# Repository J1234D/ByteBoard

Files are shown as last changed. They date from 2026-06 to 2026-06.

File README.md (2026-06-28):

# ByteBoard

ByteBoard is my custom 3×3 mechanical macropad powered by the Seeed Studio XIAO RP2040. It has 9 programmable mechanical keys, a rotary encoder, a 0.91" OLED display, per-key RGB lighting, and a custom PCB and 3D-printed case that I designed from scratch.

I started this project as part of Hack Club Stardance because I wanted to learn PCB design, CAD, and keyboard firmware by building something I would actually use. Instead of modifying an existing design, I challenged myself to design everything—from the schematic and PCB to the enclosure and firmware.

The result is a compact macropad that's useful for coding, video editing, media controls, and everyday shortcuts while also being a fun project to customize. Since everything is open source, you can easily change the firmware, modify the hardware, or even design your own version.

➡️ [Read the full journal](./JOURNAL.md)

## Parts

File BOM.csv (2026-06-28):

Id | Designator | Footprint | Quantity | Designation | Supplier and ref | Notes
1 | D1, D2, D3, D4, D5, D6, D7, D8, D9 | D_DO-35_SOD27_P7.62mm_Horizontal | 9 | 1N4148 |  | Included in Hackpad Kit
2 | D10, D11, D12, D13, D14, D15, D16, D17, D18 | LED_SK6812MINI-E_3.2x2.8mm_P1.5mm_ReverseMount | 9 | SK6812MINI-E |  | Included in Hackpad Kit
3 | SW1, SW2, SW3, SW4, SW5, SW6, SW7, SW8, SW9 | SW_Cherry_MX_1.00u_PCB_Custom | 9 | MX Switch |  | Included in Hackpad Kit
4 | SW10 | RotaryEncoder_Alps_EC11E-Switch_Vertical_H20mm | 1 | EC11 Rotary Encoder |  | Included in Hackpad Kit
5 | U1 | XIAO-Generic-Hybrid-14P-2.54-21X17.8MM | 1 | Seeed Studio XIAO RP2040 |  | Included in Hackpad Kit
6 | U2 | ER_OLEDM0.91_1x-I2C | 1 | 0.91 inch I2C OLED |  | Included in Hackpad Kit
7 | Soldering Station | N/A | 1 | YIHUA 926LED-III 60W Digital Soldering Station | https://robu.in/product/yihua-926led-iii-60w-digital-soldering-iron-tools/ | Required for assembly (not included in Hackpad Kit)

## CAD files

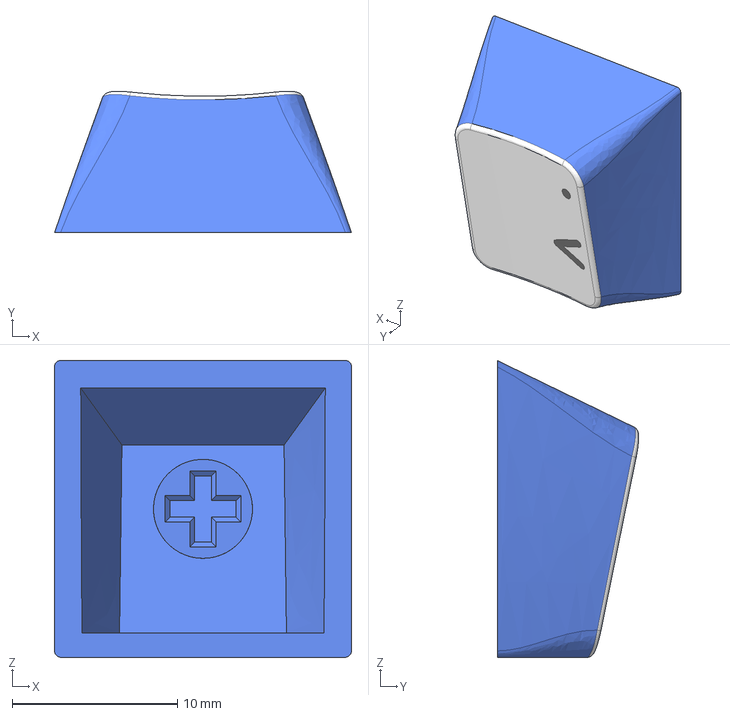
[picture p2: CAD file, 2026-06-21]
assets/CherryMX-master/r4 legended/STP/FULL STOP.stp
18.0 x 8.57 x 18.0 mm

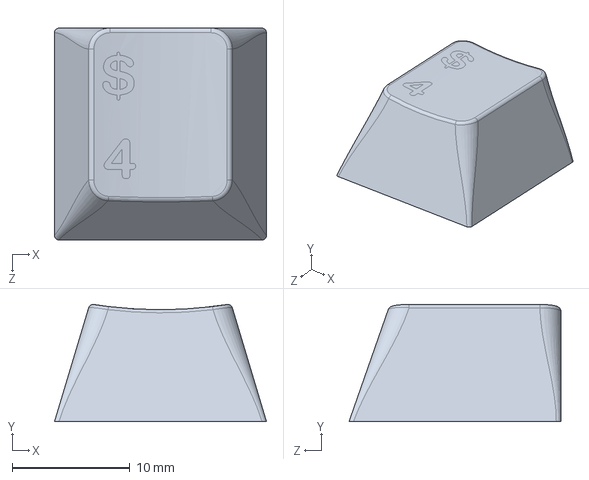
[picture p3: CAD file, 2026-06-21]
assets/CherryMX-master/r1 legended/SLDPRT/4_NEW.SLDPRT
18.0 x 9.95 x 18.0 mm

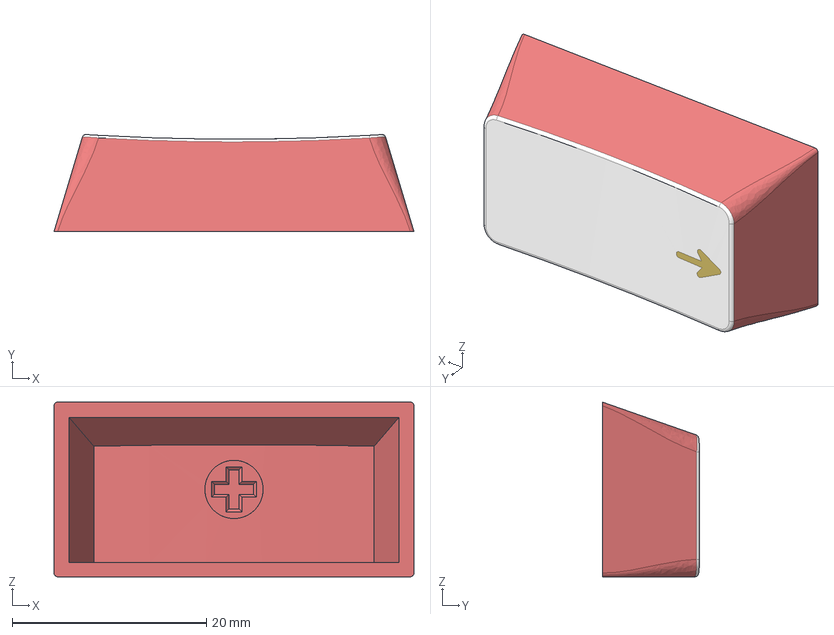
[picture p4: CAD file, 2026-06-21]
assets/CherryMX-master/r1 legended/STP/2/Backspace icon.stp
37.1 x 9.98 x 18.0 mm

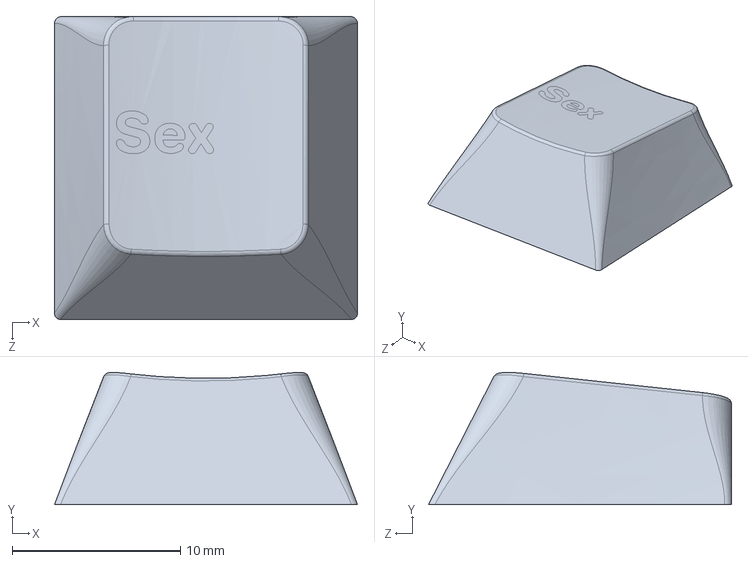
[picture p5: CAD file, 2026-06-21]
assets/CherryMX-master/r2 legended/SLDPRT/sex.SLDPRT
18.0 x 7.85 x 18.0 mm

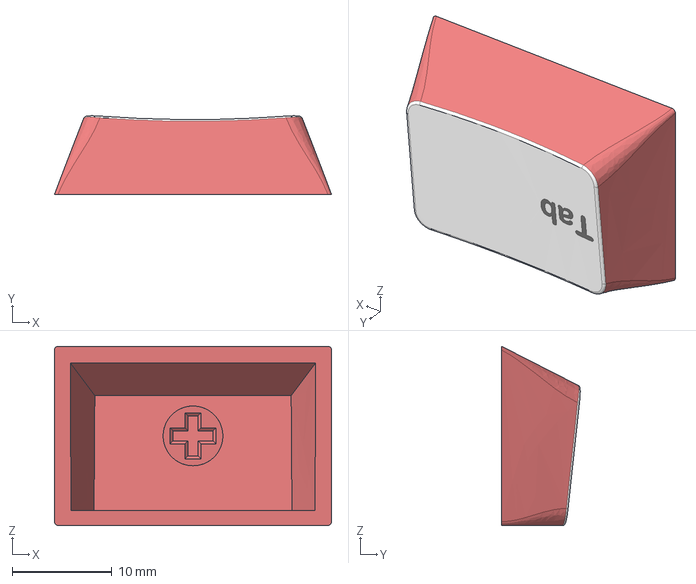
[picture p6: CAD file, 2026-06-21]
assets/CherryMX-master/r2 legended/STP/15/Tab text.stp
27.8 x 7.88 x 18.0 mm

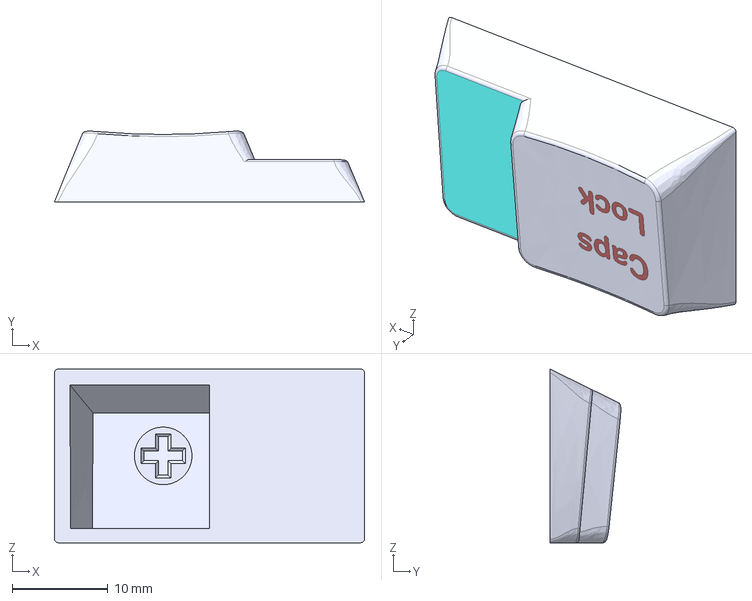
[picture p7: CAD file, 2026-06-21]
assets/CherryMX-master/r3 legended/STP/175/caps_lock_stepped.stp
32.3 x 7.36 x 18.1 mm

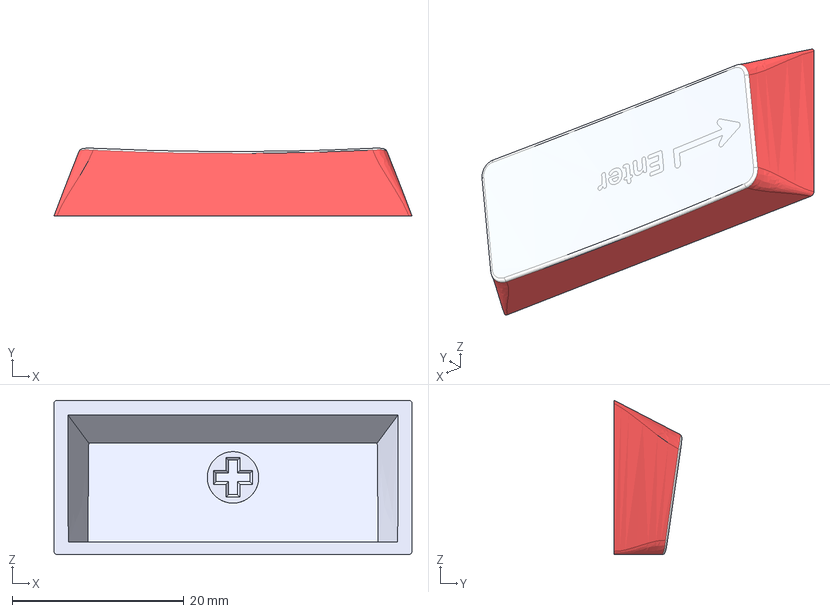
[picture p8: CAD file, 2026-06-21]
assets/CherryMX-master/r3 legended/STP/225/Enter Icon and Text 225.stp
41.7 x 7.89 x 18.0 mm

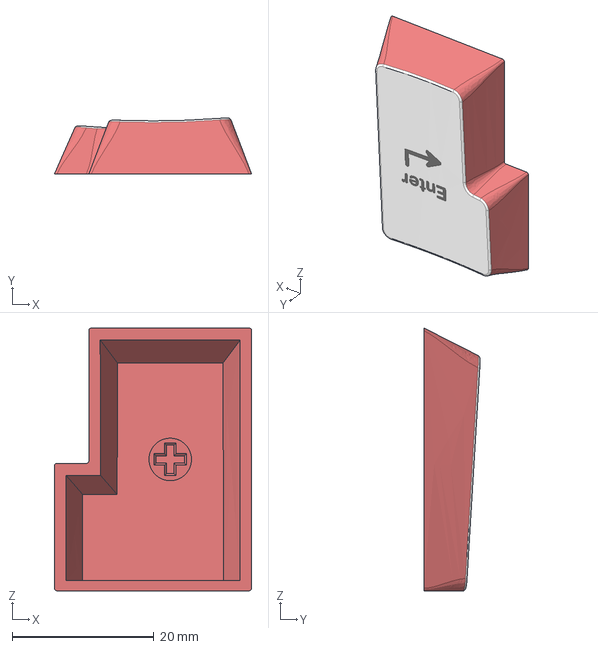
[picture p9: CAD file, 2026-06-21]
assets/CherryMX-master/r3 legended/STP/iso/Enter Icon and Text.stp
27.8 x 7.91 x 37.1 mm

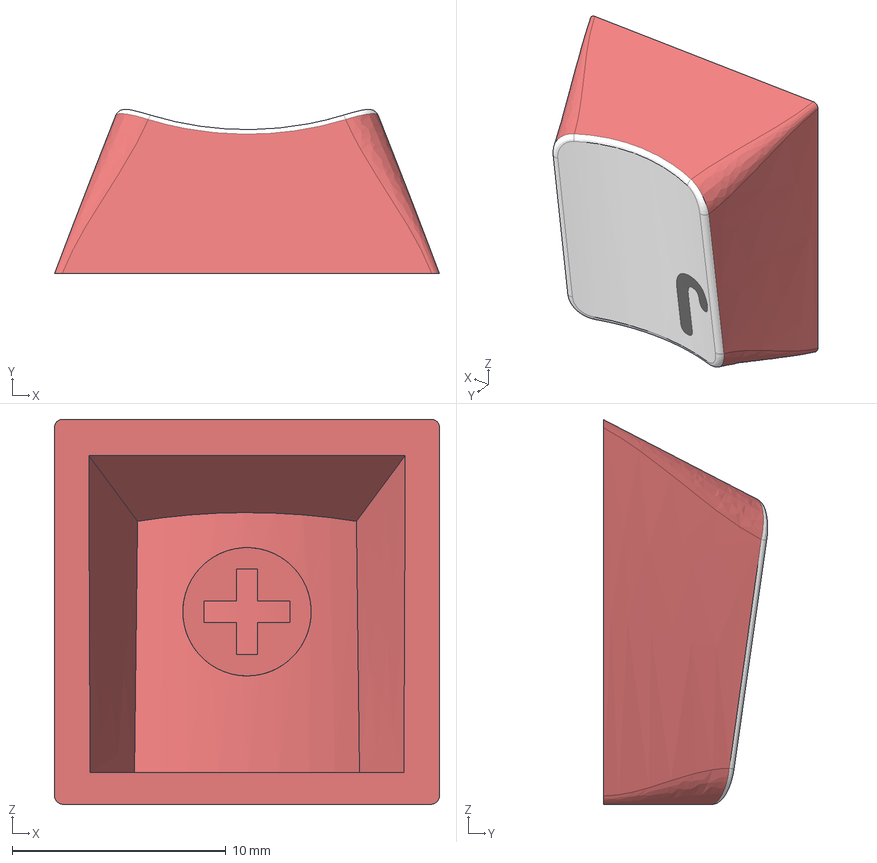
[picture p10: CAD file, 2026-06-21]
assets/CherryMX-master/r3 legended/STP/sculpted/J.stp
18.0 x 7.68 x 18.0 mm

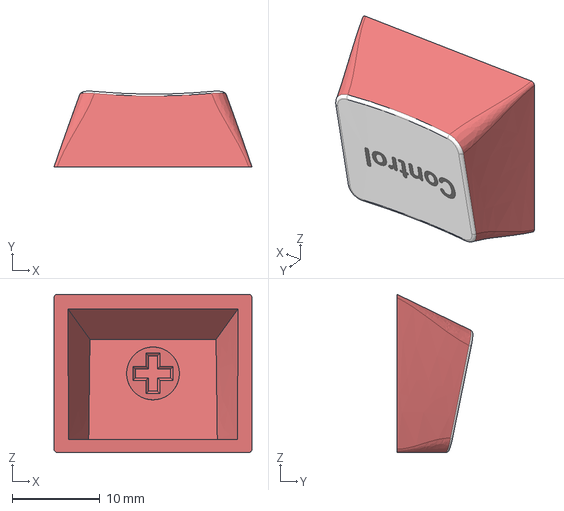
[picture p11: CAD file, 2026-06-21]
assets/CherryMX-master/r4 legended/STP/125/Control.stp
22.5 x 8.61 x 18.0 mm

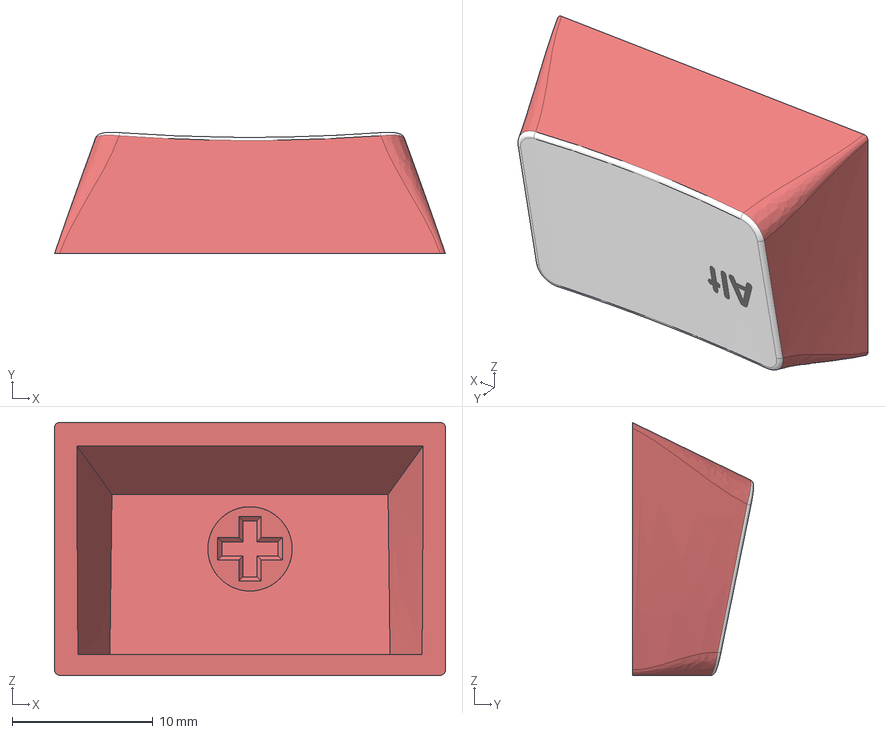
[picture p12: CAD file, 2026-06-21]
assets/CherryMX-master/r4 legended/STP/15/Alt.stp
27.8 x 8.63 x 18.0 mm

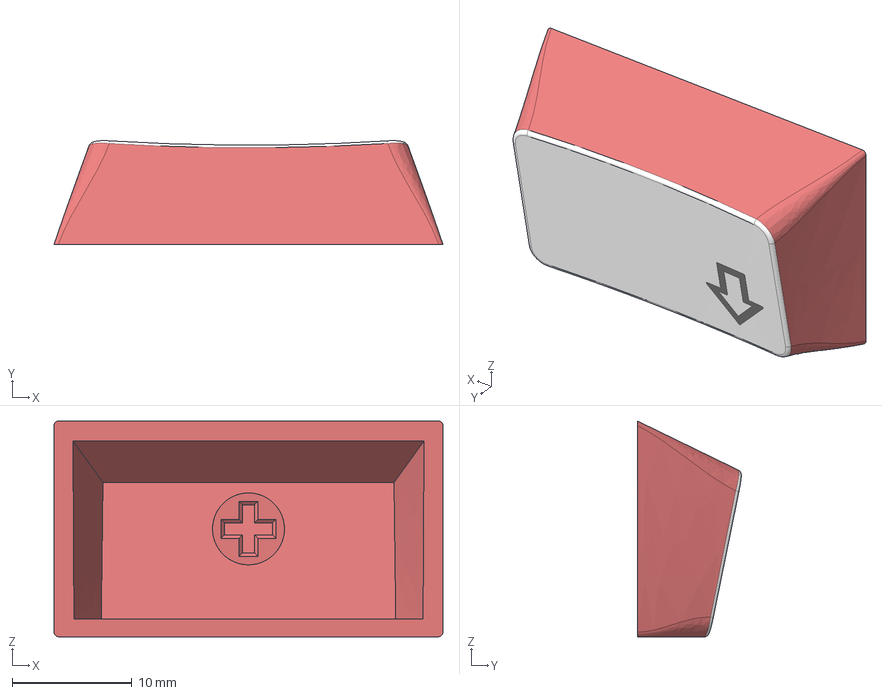
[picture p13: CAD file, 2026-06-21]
assets/CherryMX-master/r4 legended/STP/175/Shift short icon.stp
32.4 x 8.65 x 18.0 mm

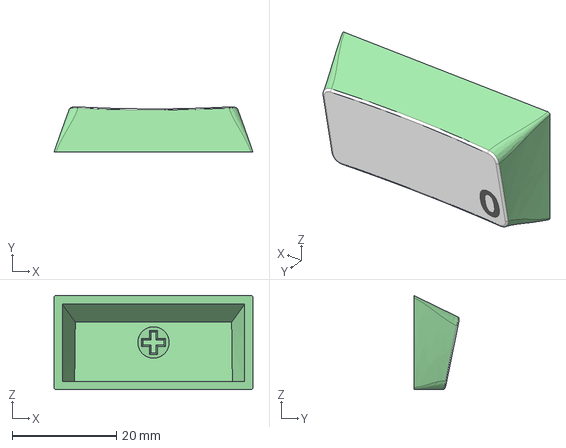
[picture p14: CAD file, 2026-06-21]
assets/CherryMX-master/r4 legended/STP/200/num0_200_mono.stp
38.1 x 8.66 x 18.0 mm

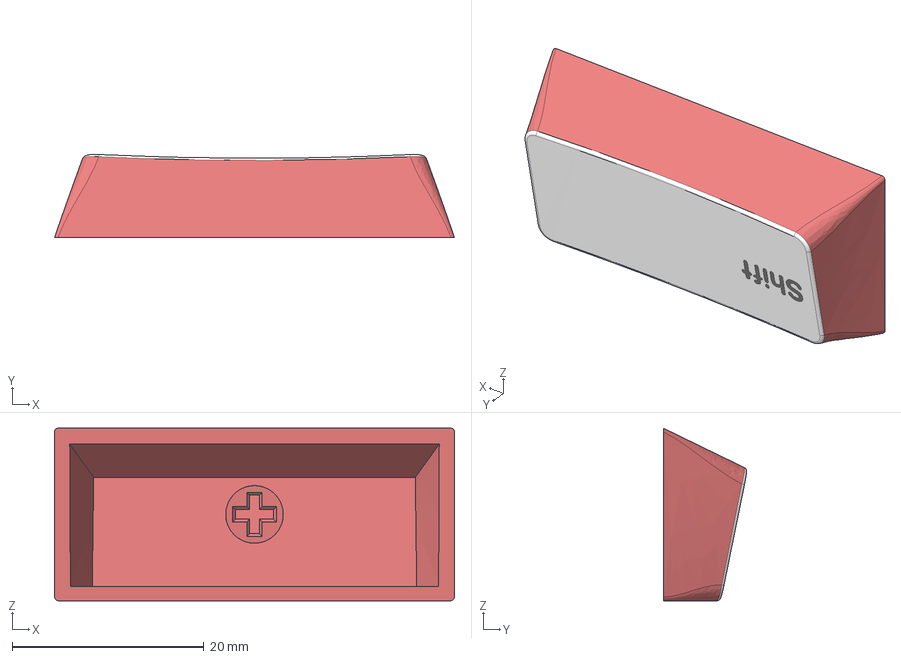
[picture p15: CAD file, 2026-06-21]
assets/CherryMX-master/r4 legended/STP/225/Shift text.stp
41.7 x 8.67 x 18.0 mm

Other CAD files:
assets/CherryMX-master/r1 legended/STP/NUM Divide.stp
assets/CherryMX-master/r2 legended/STP/NUM Minus.stp
assets/CherryMX-master/r3 legended/STP/NUM 5_homing_bar.stp
assets/CherryMX-master/r4 legended/STP/275/Shift icon and text.stp
CAD/Bottom_Case.step
CAD/Top_Case.step
assets/CherryMX-master/SLDPRT/r1/r1_100.SLDPRT
assets/CherryMX-master/SLDPRT/r1/r1_200.SLDPRT
assets/CherryMX-master/SLDPRT/r2/r2_100.SLDPRT
assets/CherryMX-master/SLDPRT/r2/r2_150.SLDPRT
assets/CherryMX-master/SLDPRT/r3/r2-3_200vert.SLDPRT
assets/CherryMX-master/SLDPRT/r3/r3_100.SLDPRT
assets/CherryMX-master/SLDPRT/r3/r3_100_bar.SLDPRT
assets/CherryMX-master/SLDPRT/r3/r3_100_sculpted.SLDPRT
assets/CherryMX-master/SLDPRT/r3/r3_125.SLDPRT
assets/CherryMX-master/SLDPRT/r3/r3_150.SLDPRT
assets/CherryMX-master/SLDPRT/r3/r3_175.SLDPRT
assets/CherryMX-master/SLDPRT/r3/r3_175_stepped.SLDPRT
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

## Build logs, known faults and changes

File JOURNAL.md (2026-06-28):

# 🎛️ ByteBoard

> A custom RGB macropad powered by the Seeed Studio XIAO RP2040.

**Author:** Jishnu Dutta
**Started:** 19 June 2026
**Progress:** 🟩🟩🟩🟩🟩🟩🟩⬜⬜⬜ 70%
**Current Stage:** Waiting for Kit

---

## 📖 Overview

ByteBoard is a custom macropad built around the Seeed Studio XIAO RP2040. It features 9 mechanical keys, SK6812 MINI-E RGB LEDs, a rotary encoder, and an OLED display for customizable controls and visual feedback. The goal of this project is to create a compact and visually appealing productivity tool while learning PCB design, electronics, and firmware development.

---

## 📅 Devlogs

# Day 0 — 19.06.2026: Planning & Studying

Just a few days ago, my friend Sunrit Hazra showed me his custom macropad, which he had built using Hack Club Blueprint. Seeing his project and hearing about the experience inspired me to build one of my own.

Today, I decided to start the project, so I learned the basics of PCB design and schematic creation. I also made a small PCB with 4 LEDs and 2 connectors.

Time spent: 3hrs

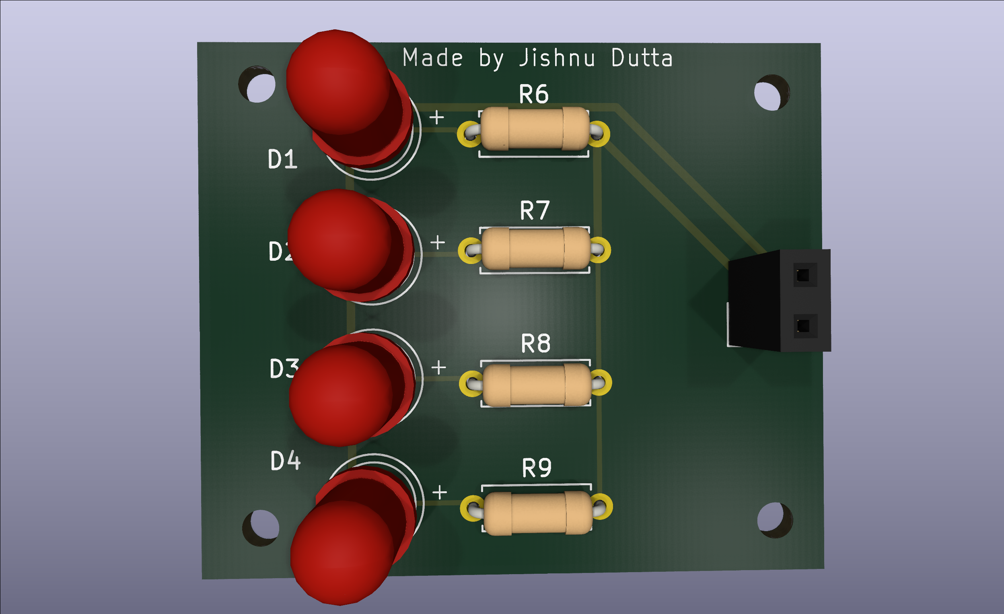
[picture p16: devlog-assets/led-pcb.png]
LED PCB


# Day 1 — 20.06.2026: Schematic

I created the 3×3 key matrix and connected it to the Seeed Studio XIAO RP2040. I also added the rotary encoder and OLED display.

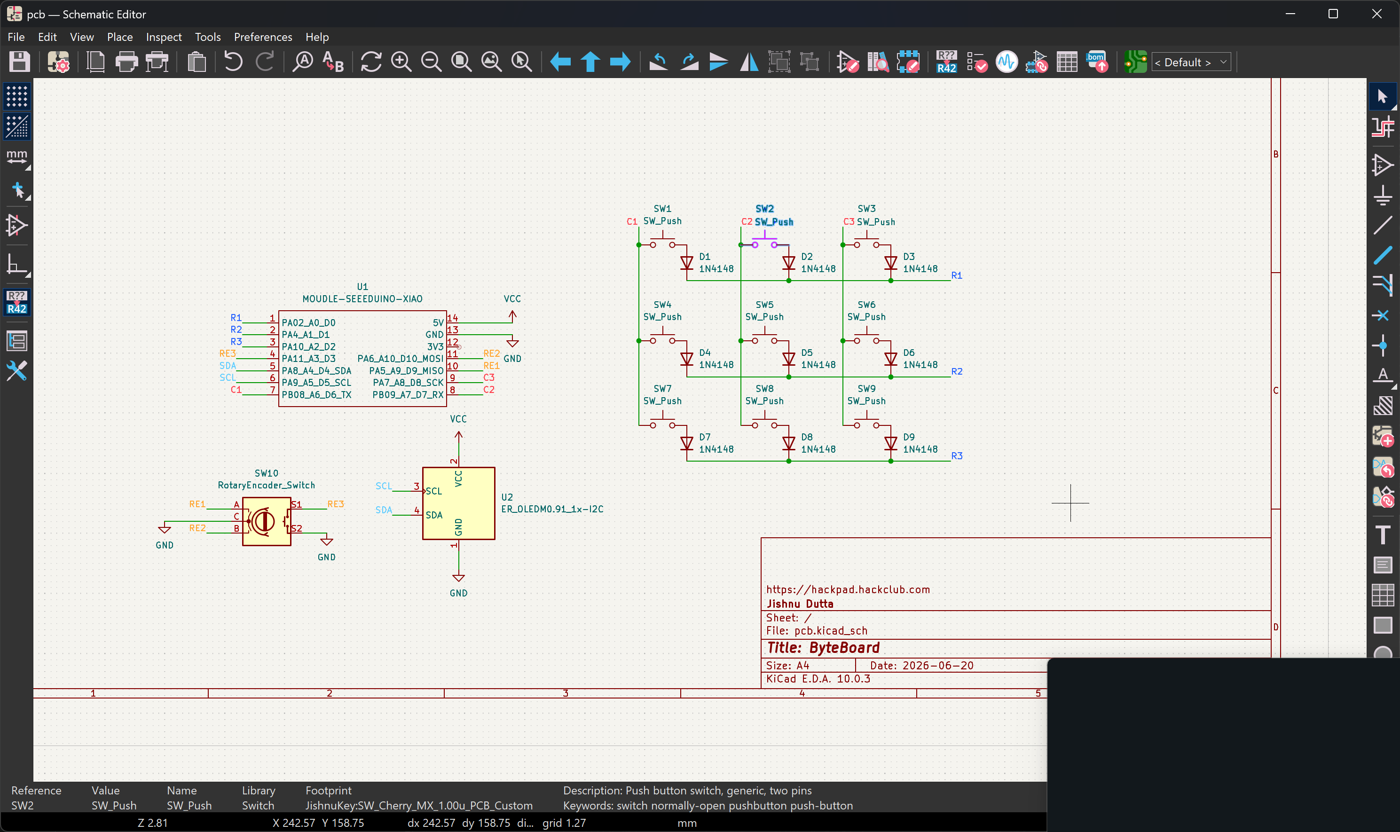
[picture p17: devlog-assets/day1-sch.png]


Time spent: 5hrs

# Day 2 — 21.06.2026: Schematic and Routing

I added SK6812 MINI-E LEDs around the edges of each key for a nice underglow effect, along with mounting holes. After that, I designed the PCB and completed the routing.

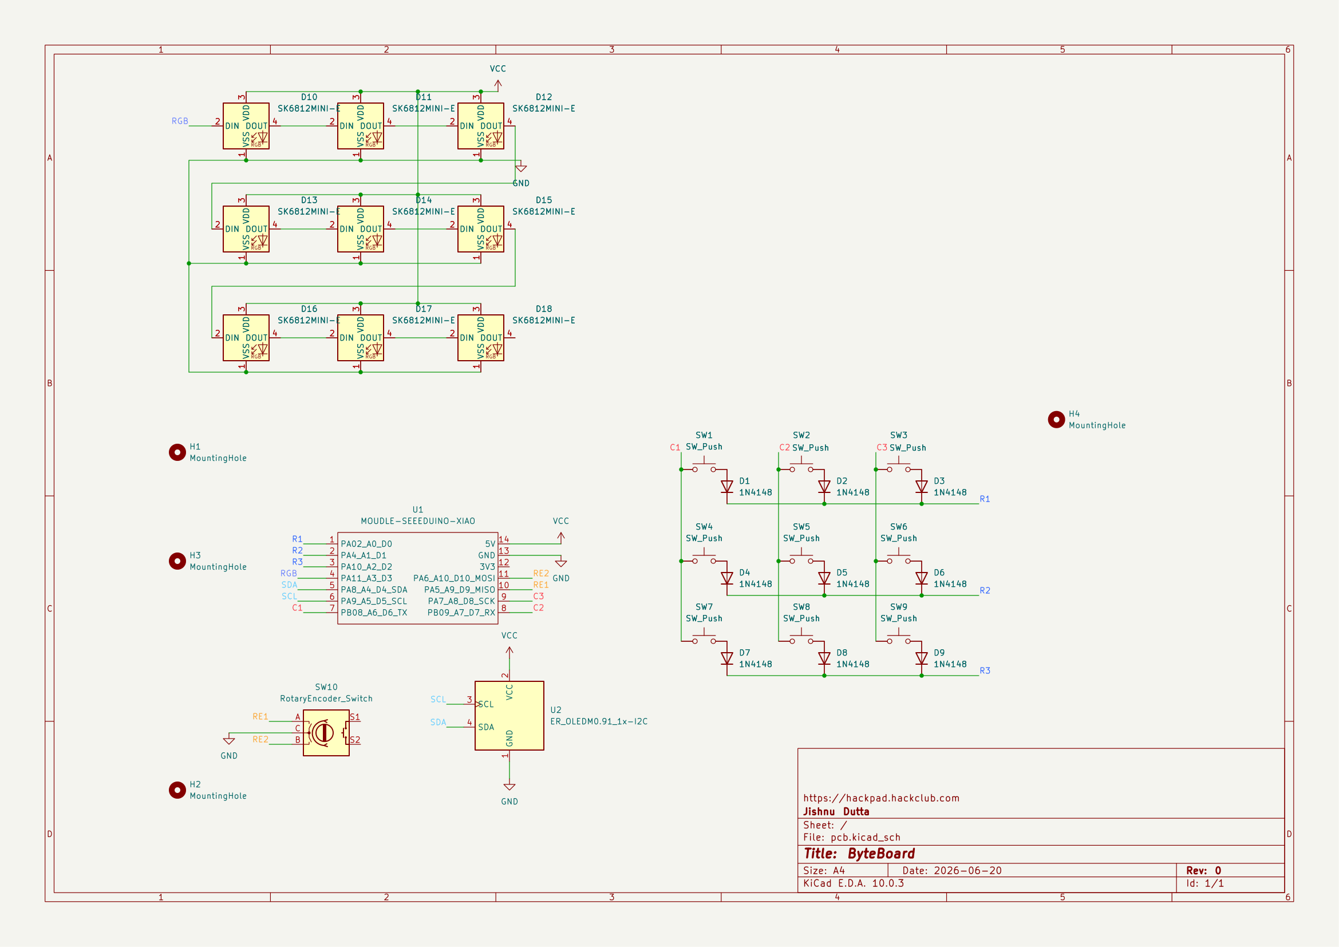
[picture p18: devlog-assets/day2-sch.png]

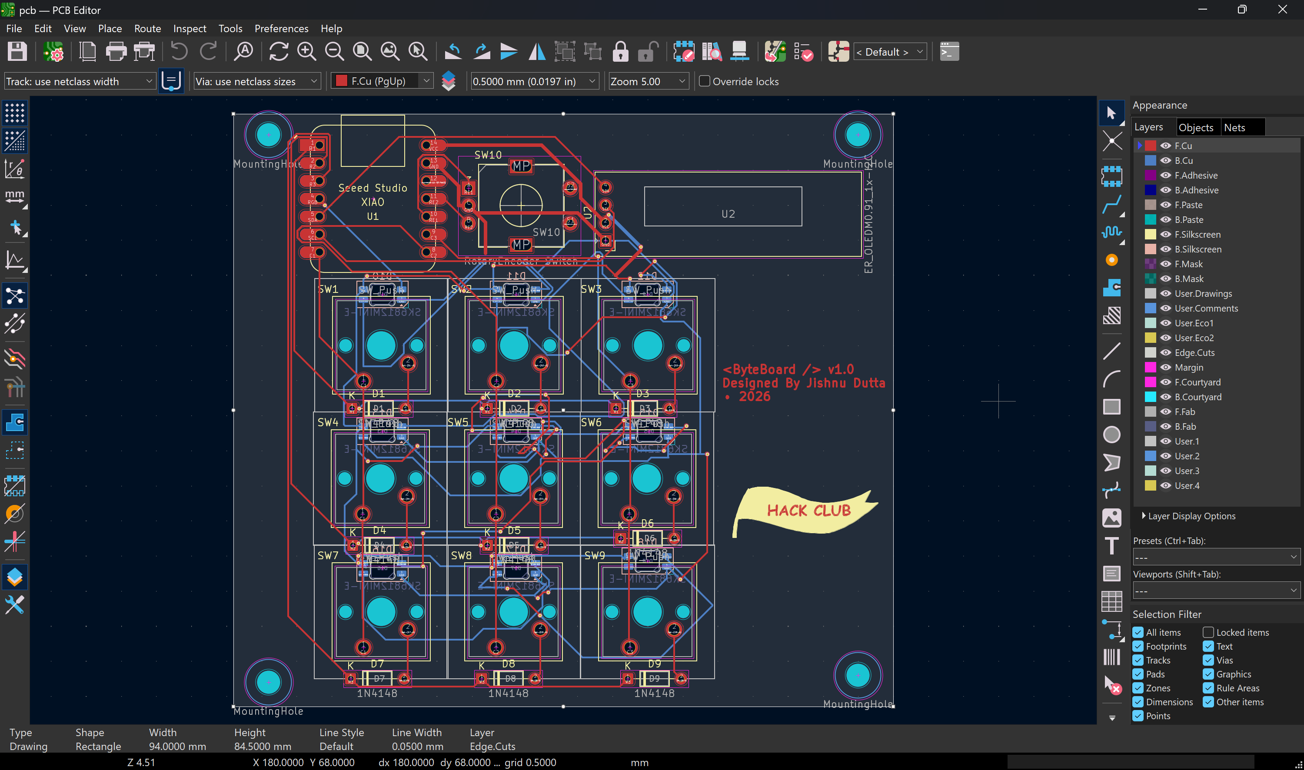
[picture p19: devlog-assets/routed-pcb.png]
PCB

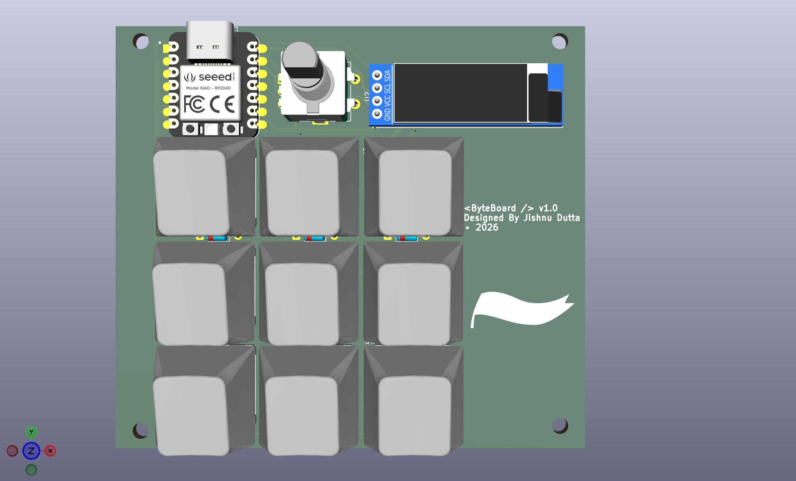
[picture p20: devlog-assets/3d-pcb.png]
3D model of PCB


Time spent: 8hrs

# Day 3 — 22.06.2026: Learning Fusion

I learned the basics of 3D modeling in Autodesk Fusion by following a tutorial and creating a small screw bracket.

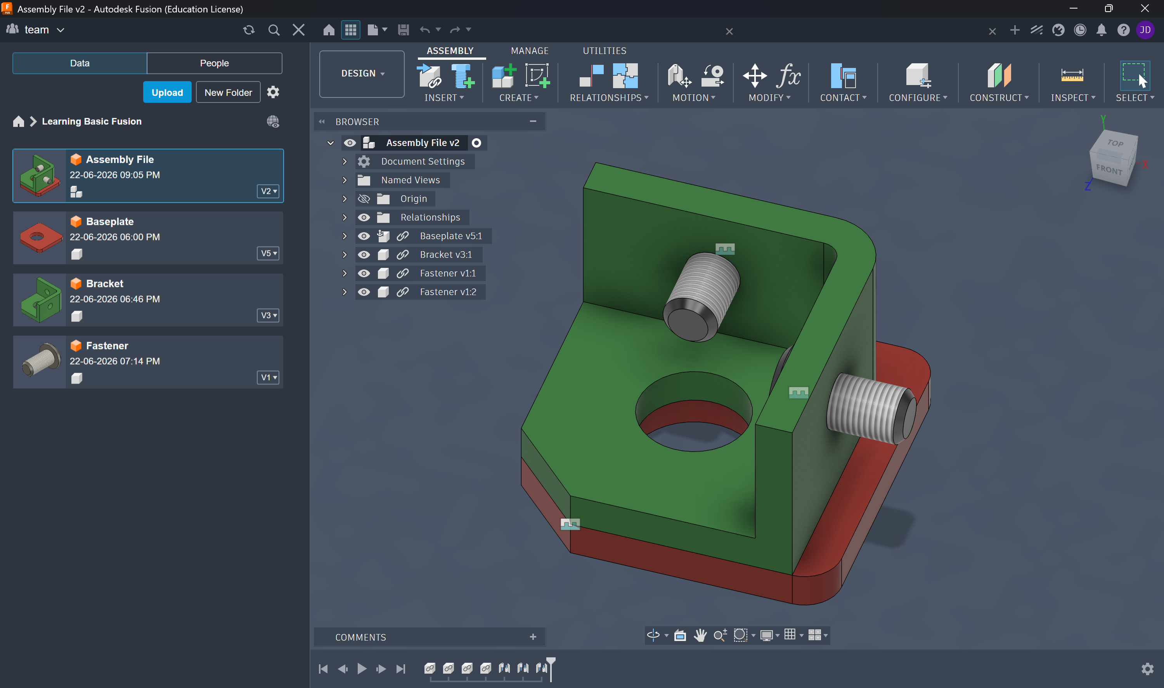
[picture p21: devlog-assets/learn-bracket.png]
bracket


Time spent: 2hrs

Sorry for not recording timelapses during the first three days. I will provide timelapse links for every day from now on.

# Day 4 — 23.06.2026: Starting the Case and Learning Fusion Tools

I researched the soldering equipment I might need for this project and started designing the bottom plate of the case. 

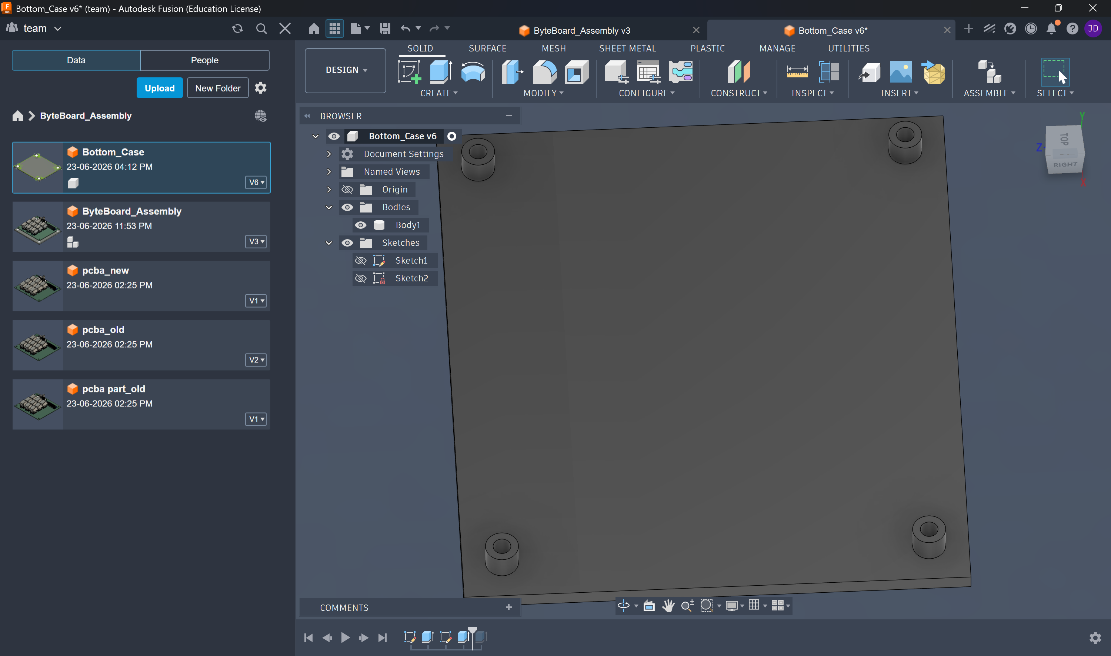
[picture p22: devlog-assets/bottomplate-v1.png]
bottomplate


Time spent: 7hrs

Lapse link: <a href="https://lapse.hackclub.com/timelapse/p2R1_J-4u7W7">Day 4</a>

# Day 5 — 25.06.2026: Fixing the Case 
I fixed the standoffs, added walls in the bottom part of the case. I also had to fix many clearance issues to make the usb type c port usable.

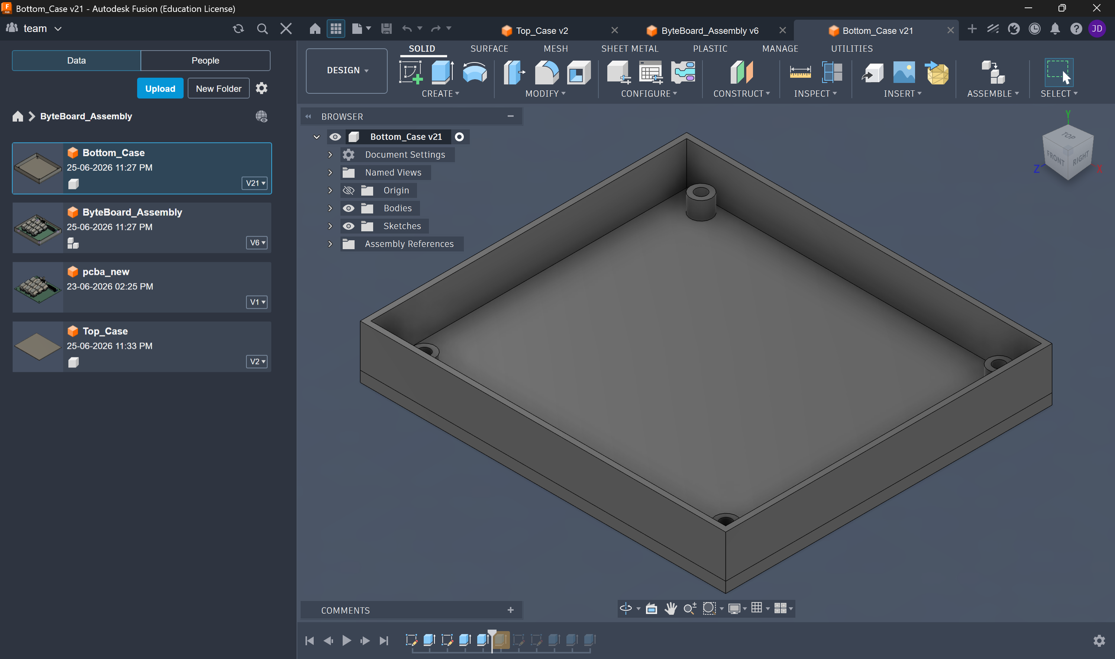
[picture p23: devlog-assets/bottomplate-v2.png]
pcb with bottomplate


Time spent: 3 hrs

Lapse link: <a href="https://lapse.hackclub.com/timelapse/Zt0mHt_HGtjv">Day 5</a>

# Day 6 — 26.06.2026: Designing the Top Case

Today I finished designing the top case. I added all the required cutouts, including the MX switch openings, OLED display window, rotary encoder hole, USB Type-C port opening, and the mounting holes. Getting the clearances right took quite a bit of tweaking, especially around the USB port.

> **Note:** The Lapse website was offline for most of the day, so I could only record about **30 minutes**, even though I worked for **around 3 hours**.

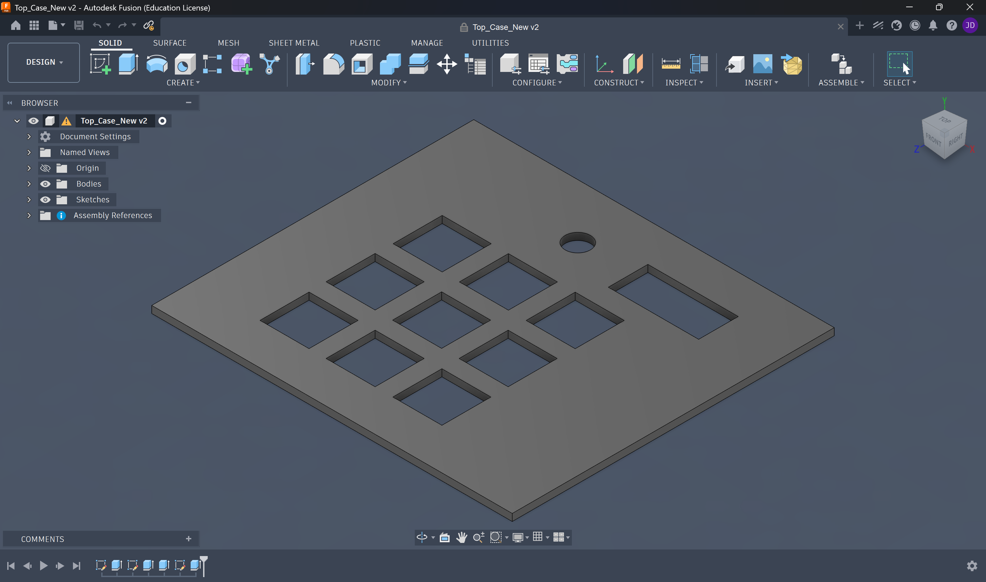
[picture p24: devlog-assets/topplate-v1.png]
Top case with all cutouts

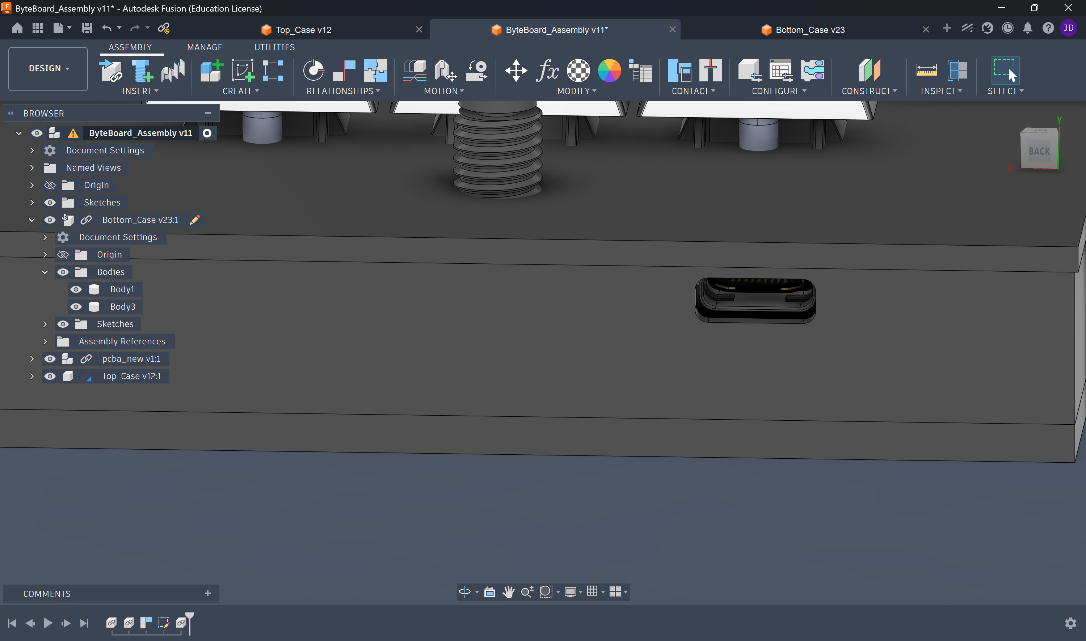
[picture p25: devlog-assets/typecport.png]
USB type-C port


**Time spent:** 3 hrs

**Lapse link:** <a href="https://lapse.hackclub.com/timelapse/NO5s9hQjbQ5v">Day 6</a>
(Only ~30 minutes recorded due to Lapse downtime.)

---

# Day 7 — 27.06.2026: Heat-Set Inserts & Final Touches

Today I redesigned the mounting system to support **M3 × 5 × 4 mm heat-set inserts**. I updated all the standoffs, added chamfers to make inserting the brass inserts easier, and created counterbores for the screw heads. I also started refining the overall appearance by rounding the outer corners of the top case.

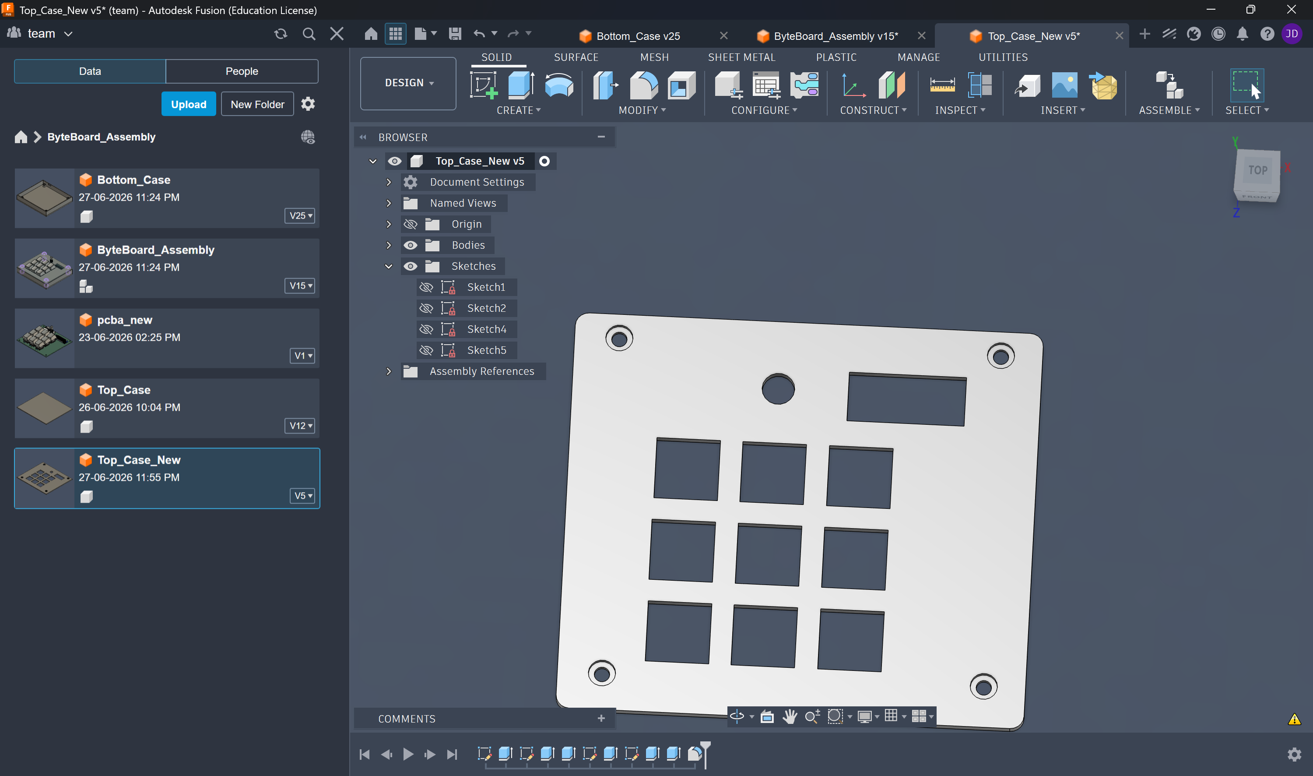
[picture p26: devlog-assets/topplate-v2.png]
Heat-set insert support and rounded corners


**Time spent:** 2 hrs

**Lapse link:** <a href="https://lapse.hackclub.com/timelapse/U-9jxX9-YpG4">Day 7</a>

# Day 8 — 28.06.2026: Completed case and firmware(Ready to Ship)

Today I finalized the enclosure by adding colours, refining the rounded corners, and making the final adjustments to the overall design. After finishing the CAD work, I started learning CircuitPython and wrote a simple temporary firmware so the macropad would be functional for the initial build. With everything ready, I submitted the project for shipping.

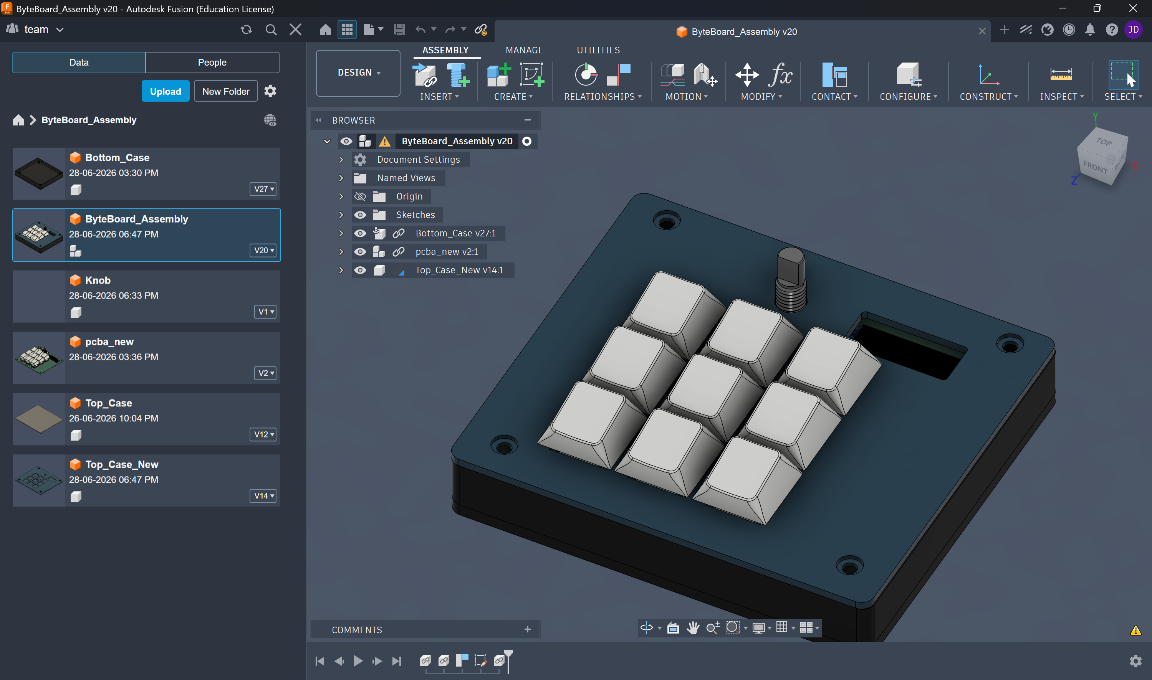
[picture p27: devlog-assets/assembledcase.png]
assembled case


**Time spent:** 4.5 hrs

**Lapse link:** <a href="https://lapse.hackclub.com/timelapse/_NHgY39VfMSt">Day 8</a>

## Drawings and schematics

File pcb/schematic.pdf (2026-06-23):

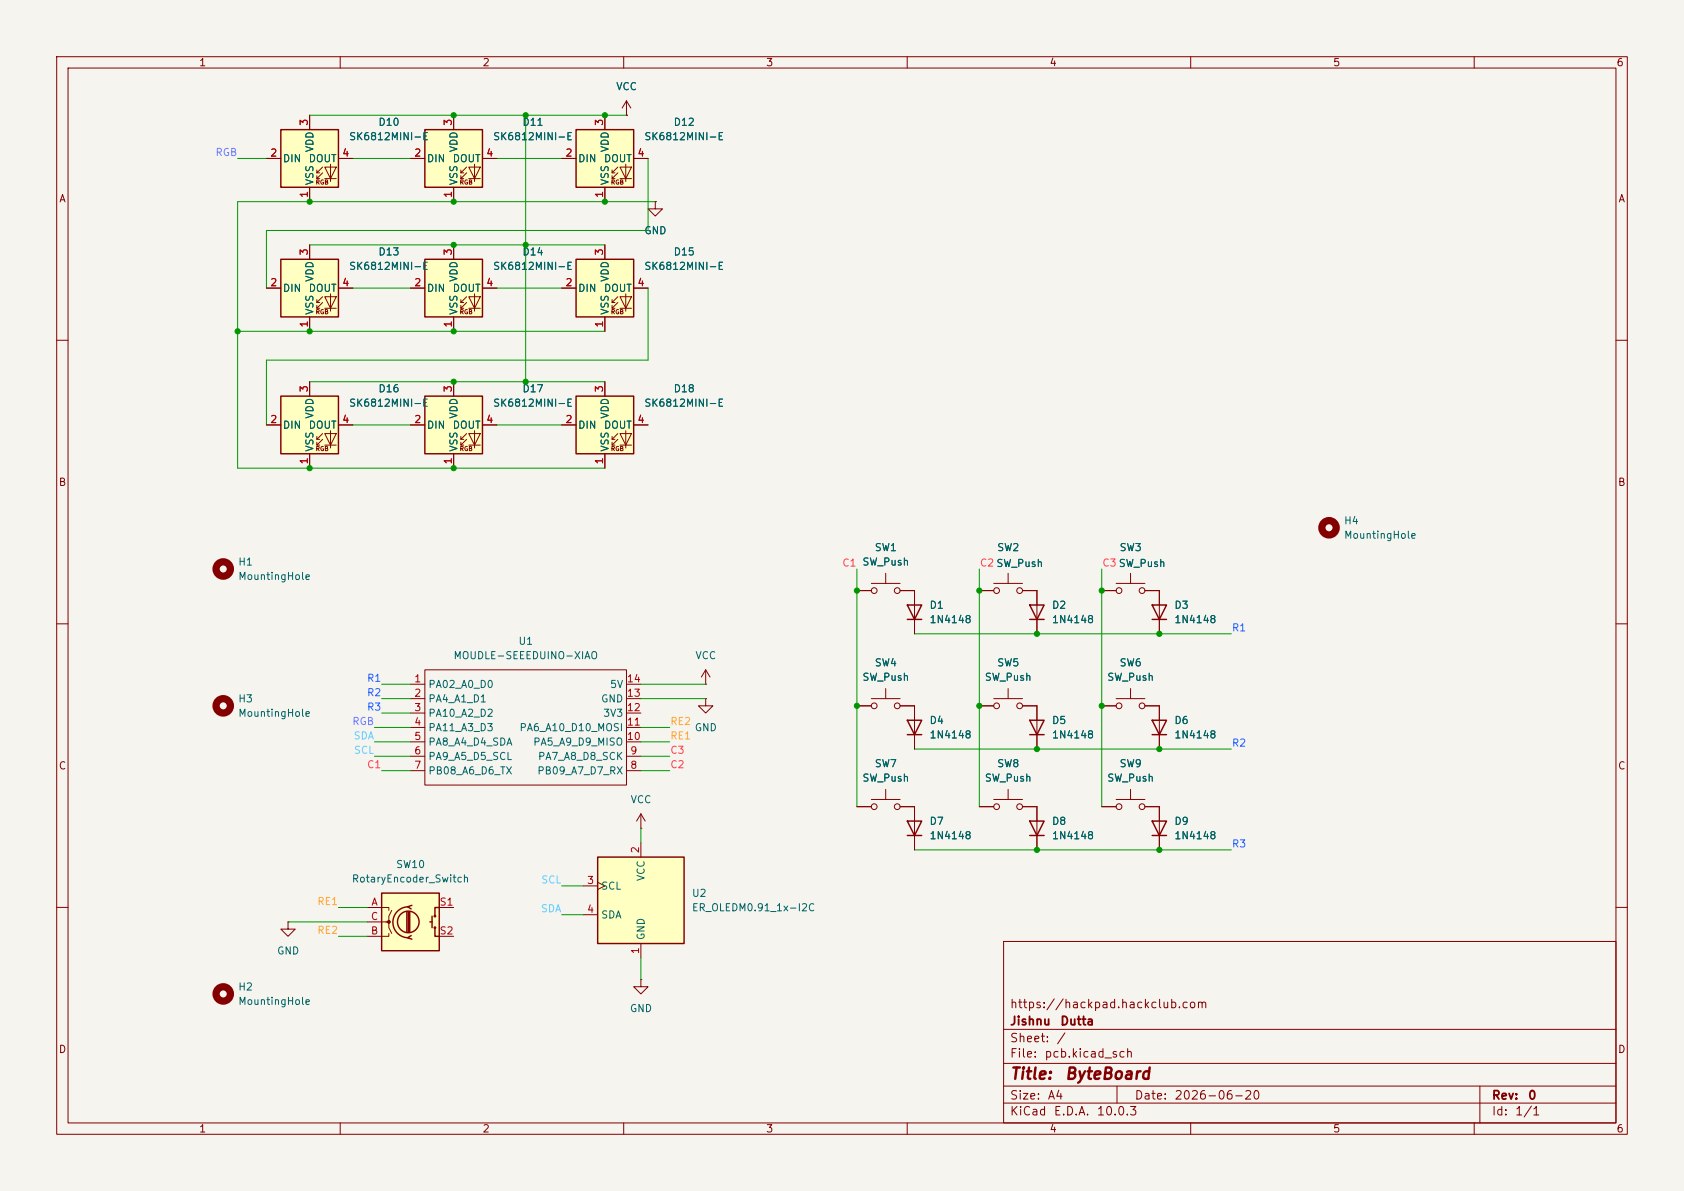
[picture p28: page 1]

https://hackpad.hackclub.com
Jishnu Dutta
Sheet: /
File: pcb.kicad_sch
Title: ByteBoard

Size: A4 | Rev: 0
KiCad E.D.A. 10.0.3 | Id: 1/1

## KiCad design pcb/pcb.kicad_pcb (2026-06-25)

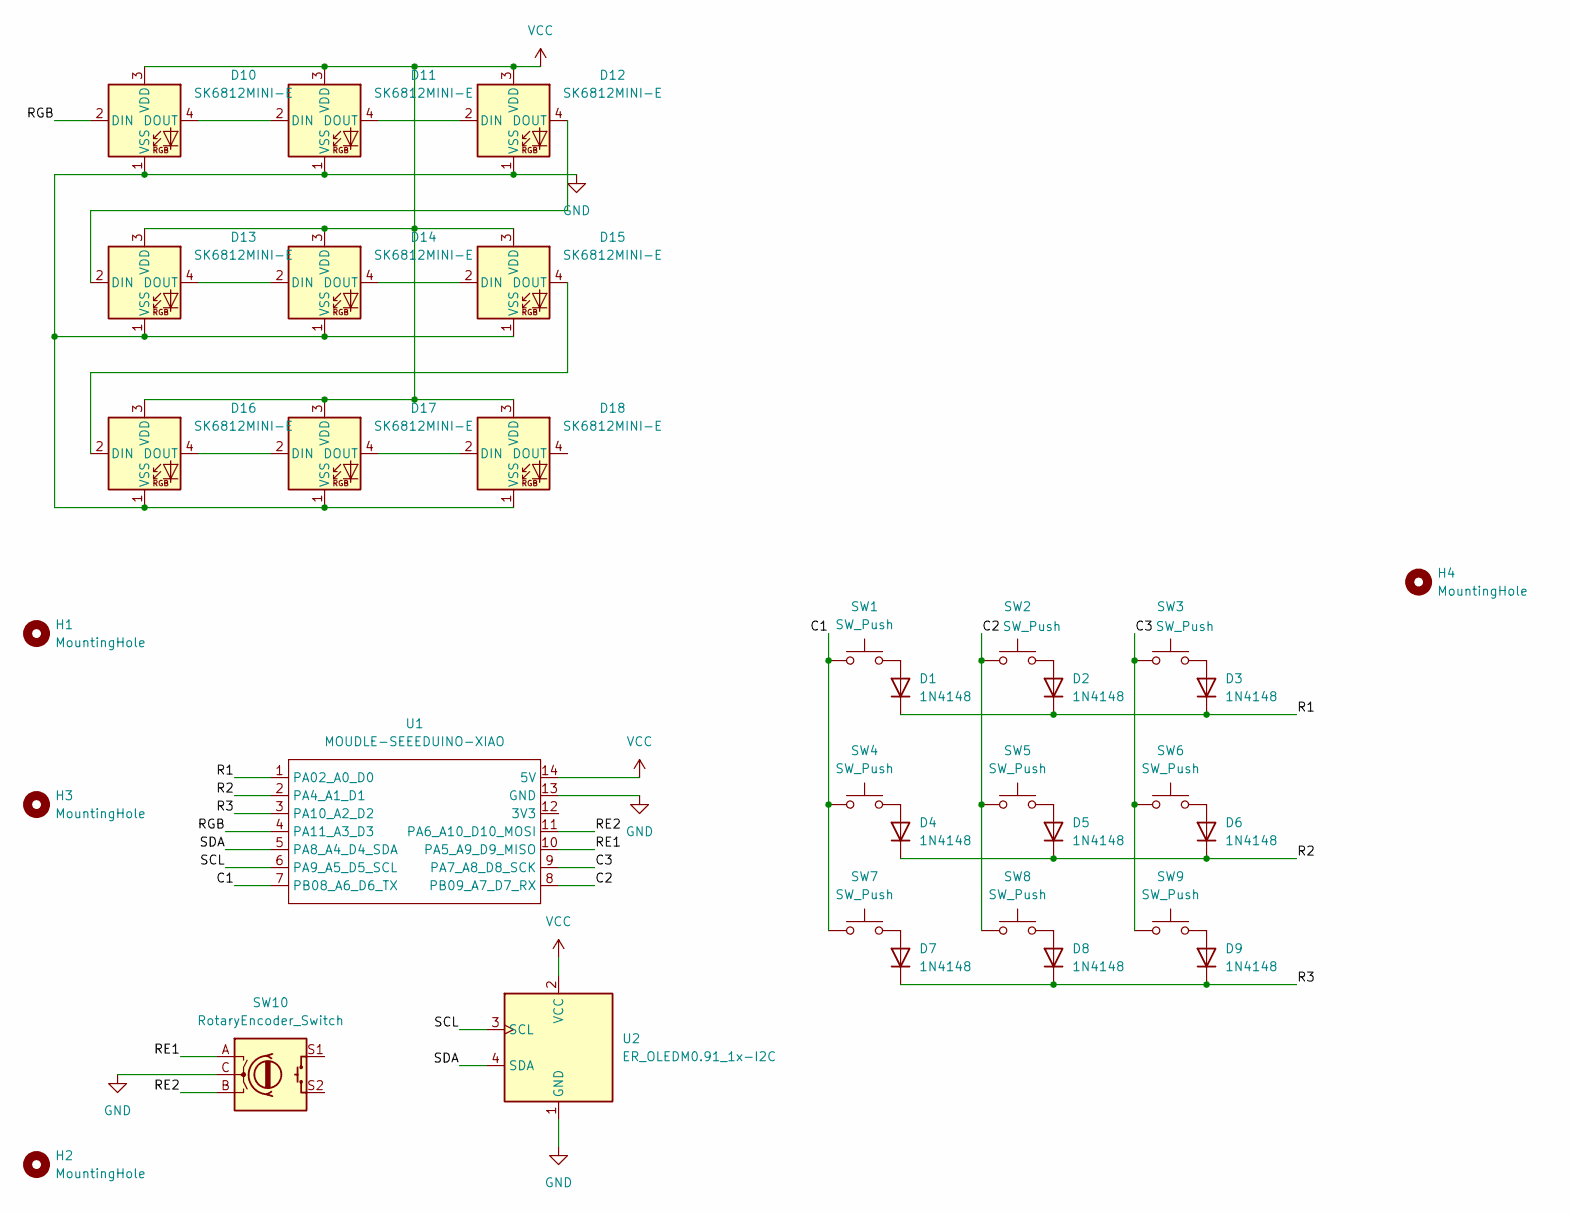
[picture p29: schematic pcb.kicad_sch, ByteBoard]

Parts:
D1, D2, D3, D4, D5, D6, D7, D8, D9: 1N4148; D_DO-35_SOD27_P7.62mm_Horizontal
D10, D11, D12, D13, D14, D15, D16, D17, D18: SK6812MINI-E; LED_SK6812MINI-E_3.2x2.8mm_P1.5mm_ReverseMount
H1, H2, H3, H4: MountingHole; MountingHole_3.2mm_M3
SW1, SW2, SW3, SW4, SW5, SW6, SW7, SW8, SW9: SW_Push; SW_Cherry_MX_1.00u_PCB_Custom
SW10: RotaryEncoder_Switch; RotaryEncoder_Alps_EC11E-Switch_Vertical_H20mm
U1: MOUDLE-SEEEDUINO-XIAO; XIAO-Generic-Hybrid-14P-2.54-21X17.8MM
U2: ER_OLEDM0.91_1x-I2C

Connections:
/C1: SW1.1, SW4.1, SW7.1, U1.7 (PB08_A6_D6_TX)
/C2: SW2.1, SW5.1, SW8.1, U1.8 (PB09_A7_D7_RX)
/C3: SW3.1, SW6.1, SW9.1, U1.9 (PA7_A8_D8_SCK)
/R1: D1.1 (K), D2.1 (K), D3.1 (K), U1.1 (PA02_A0_D0)
/R2: D4.1 (K), D5.1 (K), D6.1 (K), U1.2 (PA4_A1_D1)
/R3: D7.1 (K), D8.1 (K), D9.1 (K), U1.3 (PA10_A2_D2)
/RE1: SW10.A, U1.10 (PA5_A9_D9_MISO)
/RE2: SW10.B, U1.11 (PA6_A10_D10_MOSI)
/RGB: D10.2 (DIN), U1.4 (PA11_A3_D3)
/SCL: U1.6 (PA9_A5_D5_SCL), U2.3 (SCL)
/SDA: U1.5 (PA8_A4_D4_SDA), U2.4 (SDA)
GND: D10.1 (VSS), D11.1 (VSS), D12.1 (VSS), D13.1 (VSS), D14.1 (VSS), D15.1 (VSS), D16.1 (VSS), D17.1 (VSS), D18.1 (VSS), SW10.C, U1.13 (GND), U2.1 (GND)
unnamed: D1.2 (A), SW1.2
unnamed: D2.2 (A), SW2.2
unnamed: D3.2 (A), SW3.2
unnamed: D4.2 (A), SW4.2
unnamed: D5.2 (A), SW5.2
unnamed: D6.2 (A), SW6.2
unnamed: D7.2 (A), SW7.2
unnamed: D8.2 (A), SW8.2
unnamed: D9.2 (A), SW9.2
unnamed: D10.4 (DOUT), D11.2 (DIN)
unnamed: D11.4 (DOUT), D12.2 (DIN)
unnamed: D12.4 (DOUT), D13.2 (DIN)
unnamed: D13.4 (DOUT), D14.2 (DIN)
unnamed: D14.4 (DOUT), D15.2 (DIN)
unnamed: D15.4 (DOUT), D16.2 (DIN)
unnamed: D16.4 (DOUT), D17.2 (DIN)
unnamed: D17.4 (DOUT), D18.2 (DIN)
VCC: D10.3 (VDD), D11.3 (VDD), D12.3 (VDD), D13.3 (VDD), D14.3 (VDD), D15.3 (VDD), D16.3 (VDD), D17.3 (VDD), D18.3 (VDD), U1.14 (5V), U2.2 (VCC)

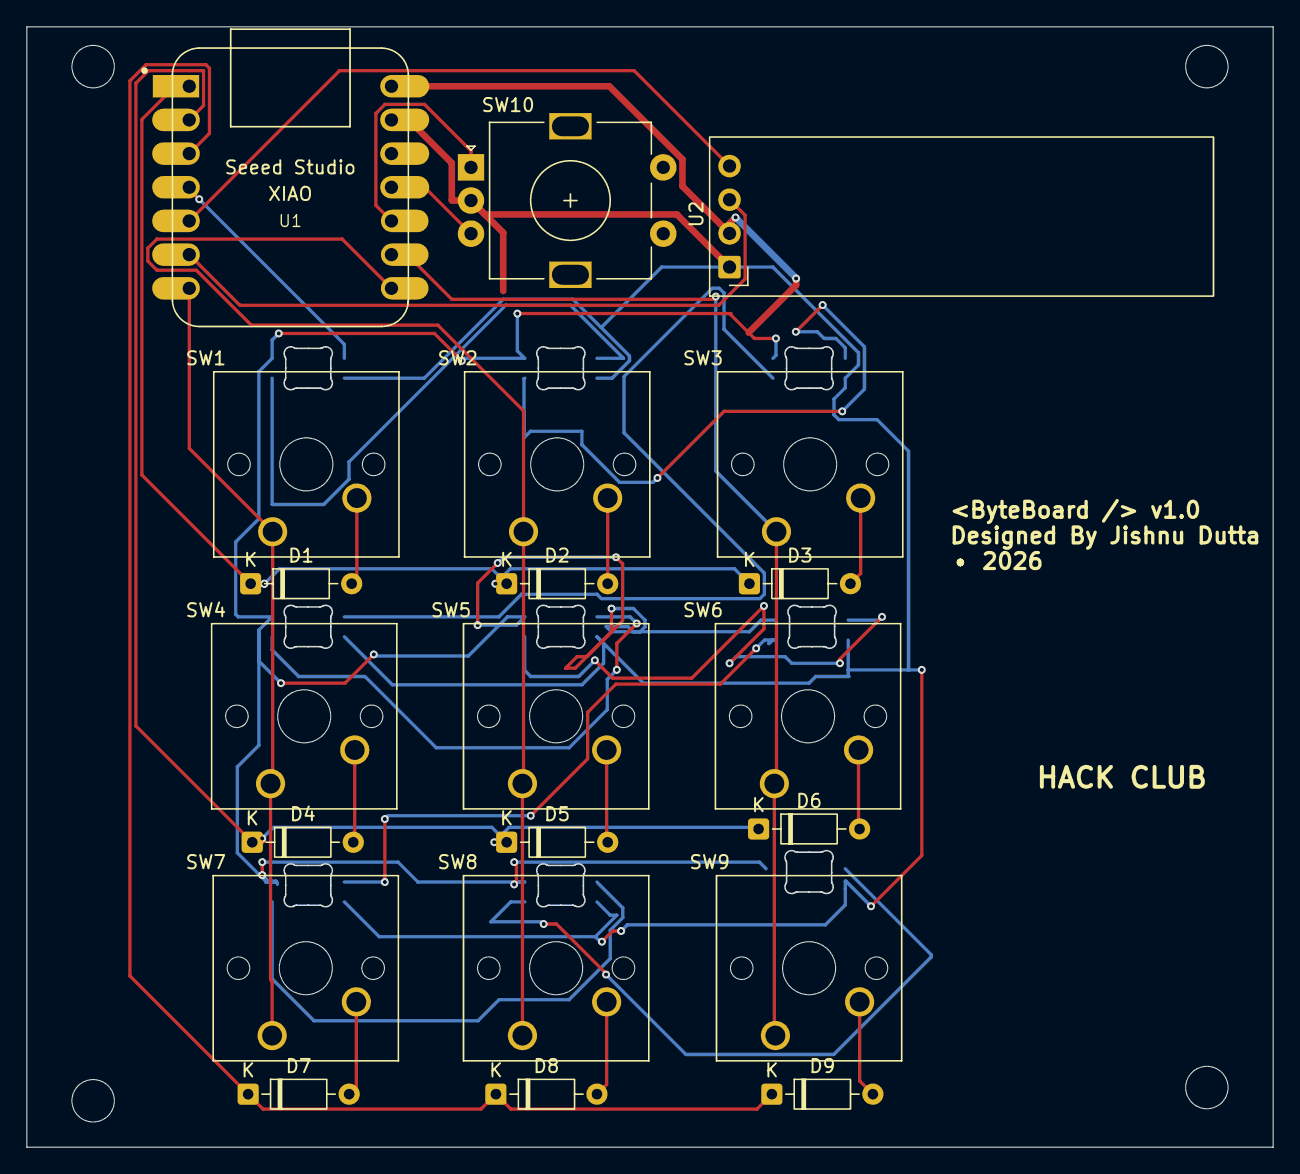
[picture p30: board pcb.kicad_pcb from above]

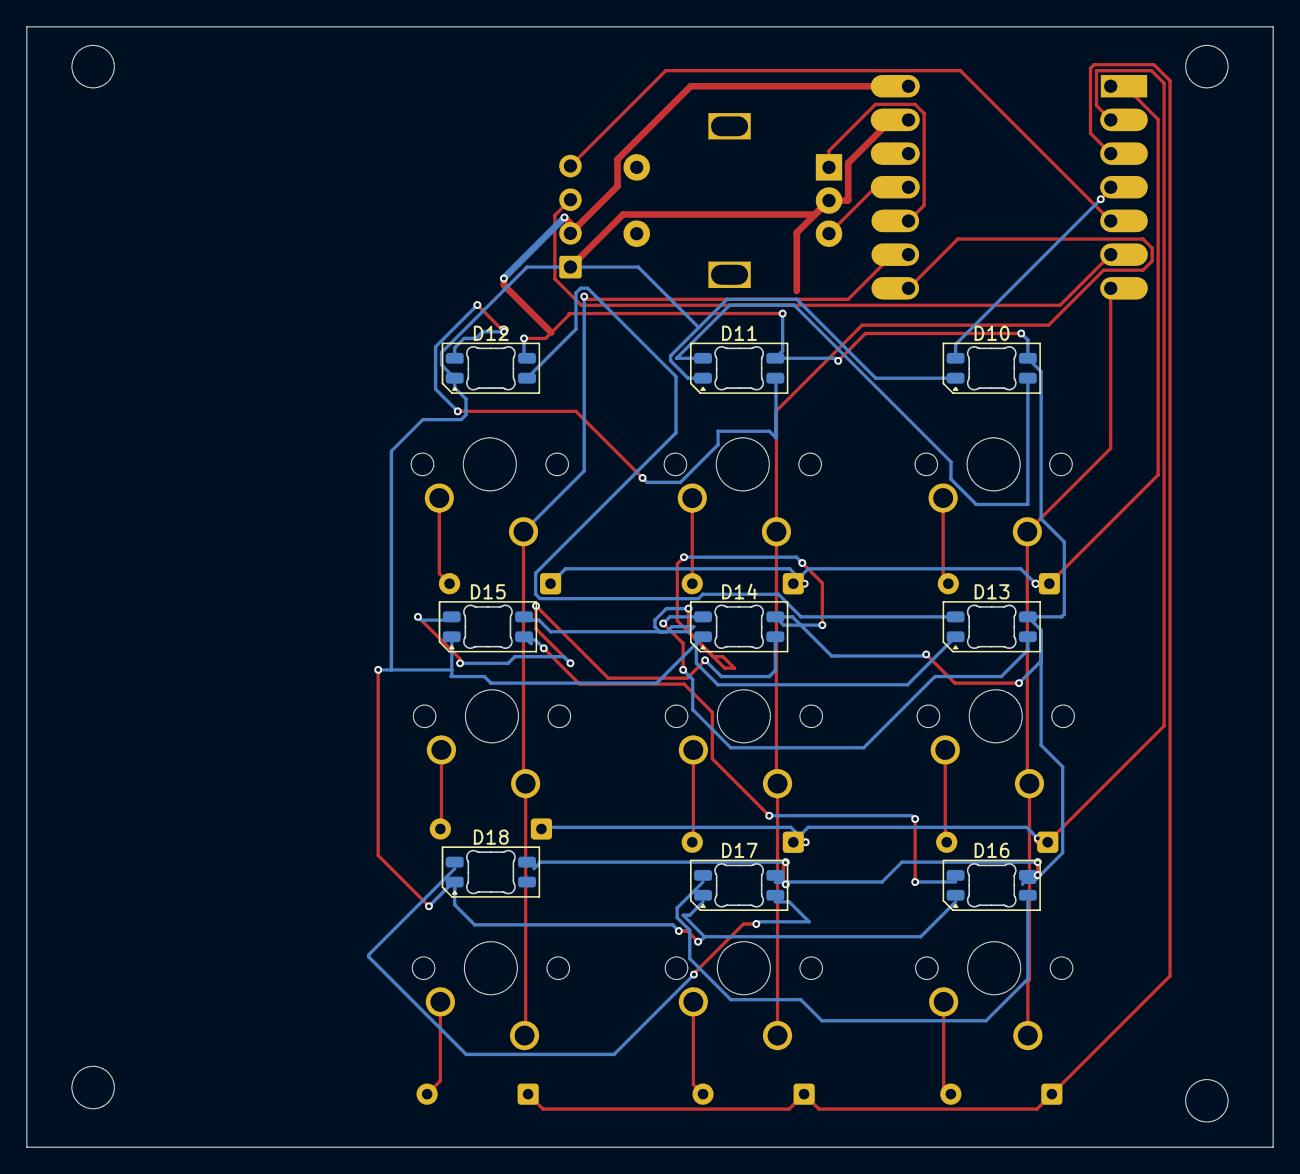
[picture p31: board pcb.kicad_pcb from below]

Board: 2 copper layers, 94.0 x 84.5 mm, 34 parts (9 on the bottom side), 30 nets.

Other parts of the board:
H3#2: MountingHole; MountingHole_3.2mm_M3

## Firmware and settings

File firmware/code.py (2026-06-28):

import board
from kmk.kmk_keyboard import KMKKeyboard
from kmk.scanners import DiodeConfiguration
from kmk.keys import KC
from kmk.modules.encoder import EncoderHandler
from kmk.extensions.media_keys import MediaKeys
from kmk.extensions.oled import OLED, OLED_DisplayMode
from kmk.extensions.RGB import RGB, AnimationModes

#temporary code(I will add new features after getting the components.)
keyboard = KMKKeyboard()

# Matrix
keyboard.col_pins = (board.D0, board.D1, board.D2)
keyboard.row_pins = (board.D3, board.D4, board.D5)
keyboard.diode_orientation = DiodeConfiguration.COL2ROW

# Encoder (Rotation Only)
encoder_handler = EncoderHandler()
keyboard.modules.append(encoder_handler)

# A, B pins only (no push button)
encoder_handler.pins = (
    (board.D6, board.D7, None),
)

encoder_handler.map = [
    (
        (KC.VOLU, KC.VOLD),
        None,
    ),
]

# OLED
oled = OLED(
    scl=board.SCL,
    sda=board.SDA,
    width=128,
    height=64,
    flip=False,
    display_mode=OLED_DisplayMode.TXT,
)

keyboard.extensions.append(oled)

# Static Blue RGB
rgb = RGB(
    pixel_pin=board.D9,
    num_pixels=9,
    animation_mode=AnimationModes.STATIC,
)

keyboard.extensions.append(rgb)

# Set static blue
rgb.set_hsv_fill(170, 255, 120)

# Media Keys
keyboard.extensions.append(MediaKeys())

# Keymap
keyboard.keymap = [
    [
        KC.VOLU, KC.MUTE, KC.VOLD,
        KC.MPRV, KC.MPLY, KC.MNXT,
        KC.COPY, KC.PASTE, KC.CUT,
    ],
]

# OLED Startup Screen
def startup():
    oled.text("ByteBoard", 0, 0, 1)
    oled.text("Hackpad v1", 0, 16, 1)
    oled.text("Ready!", 0, 32, 1)
    oled.show()

startup()

keyboard.go()

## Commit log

2026-06-20 making the schematic
    [pcb.kicad_pcb, pcb.kicad_sch]
2026-06-21 making the schematic and adding assets
    [-.SLDPRT, -.stp, 0.SLDPRT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]
2026-06-21 routing on the pcb
    [pcb.kicad_pcb, pcb.kicad_sch]
2026-06-22 add readme and logo
    [pcb.kicad_pcb]
2026-06-23 update Journal
    [pcb-B_Cu.gbr, pcb-B_Mask.gbr, pcb-B_Silkscreen.gbr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]
2026-06-25 fixed silkscreen
    [pcb-B_Cu.gbr, pcb-B_Mask.gbr, pcb-B_Silkscreen.gbr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]
2026-06-28 added CAD files
    [Bottom_Case.step, Top_Case.step]
2026-06-28 added BOM.csv
    [BOM.csv]
2026-06-28 update BOM
    [BOM.csv]
2026-06-28 updated BOM
    [BOM.csv]
